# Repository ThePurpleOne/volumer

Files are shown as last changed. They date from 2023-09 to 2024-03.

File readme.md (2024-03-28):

# Volumer
Hardware module to easily control Individual Windows app just like the volume Mixer.

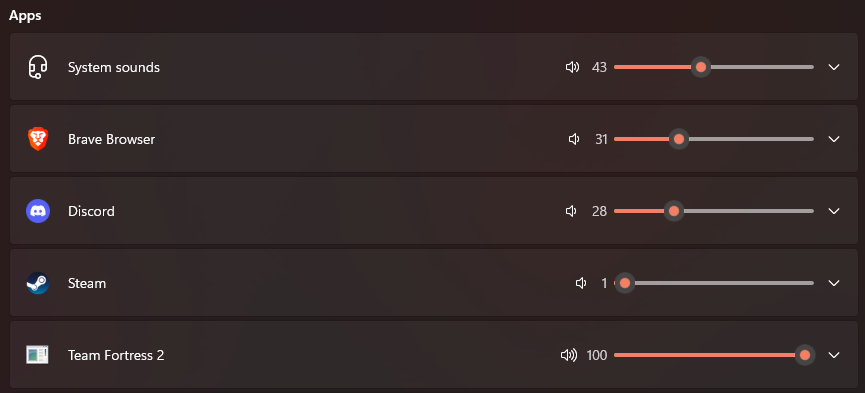
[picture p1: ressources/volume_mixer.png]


Accessing this window is a pain, especially if you're in game and you need to quickly lower that annoying SCREAMING discord friend in order to hear some terrorist footsteps.

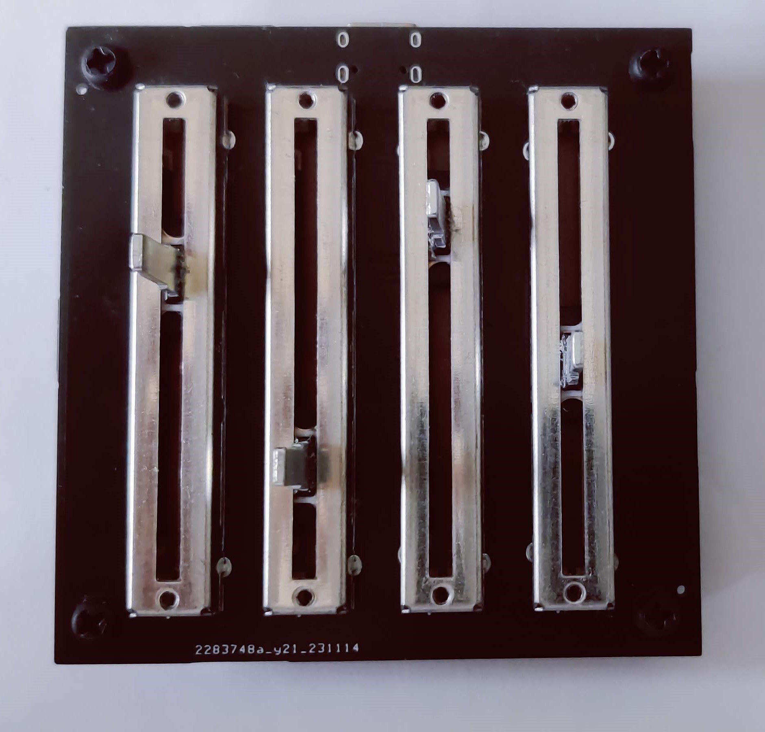
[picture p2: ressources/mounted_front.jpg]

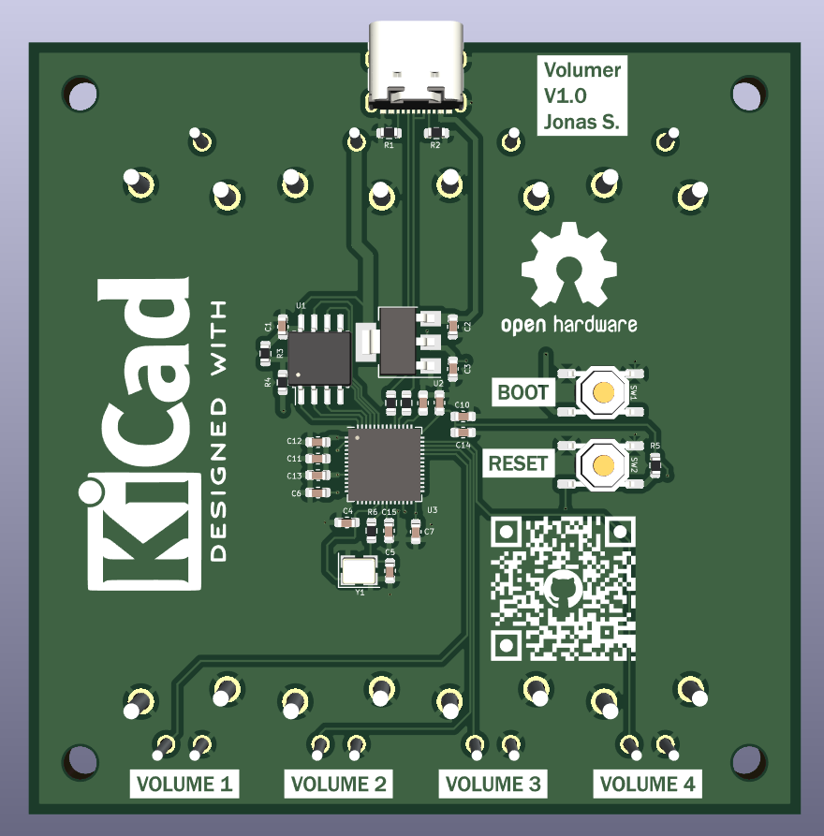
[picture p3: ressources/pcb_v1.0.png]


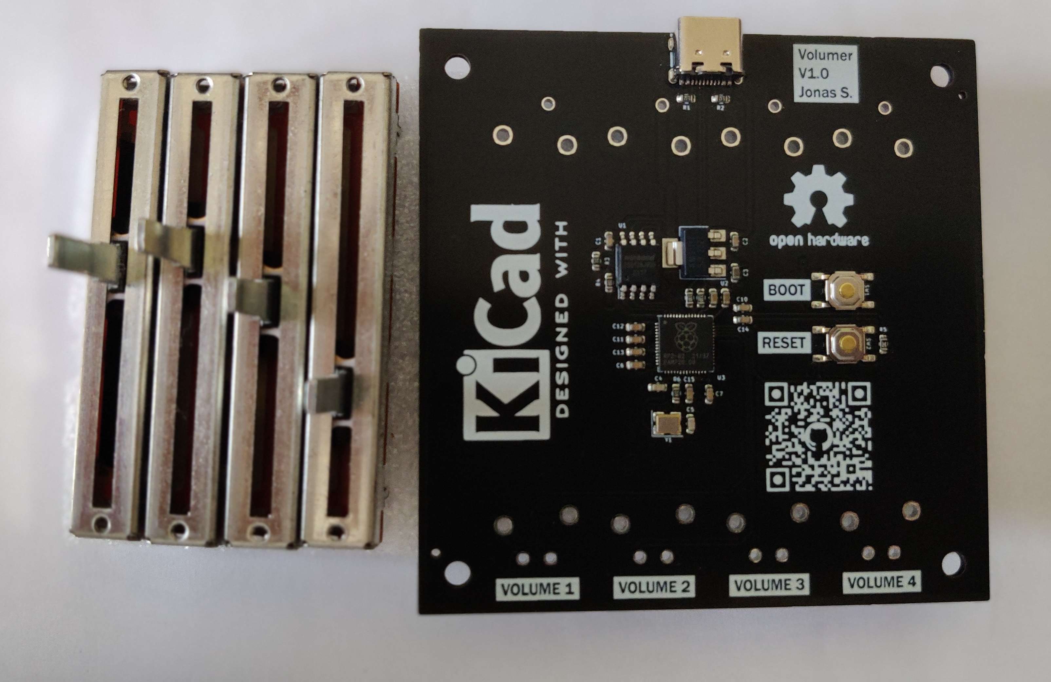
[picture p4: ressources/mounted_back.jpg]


> The PCB parts have been chosen for cheapest PCB Assembly with only 2 JLC PCB extended parts 

## How to setup
First you have to order your PCB and mount the potentiometers:
- [PCB Information](pcbs.md)
- [JLC PCB Order instructions](jlc_order.md)

Then you can install the software on the PC and flash the firmware on the Board:
- [Install the PC app](#pc-software)
- [Install/Update Board Firmware](#board-firmware)

## Case

There is no case for now, don't hesitate to contribute ! Here is the dimensions

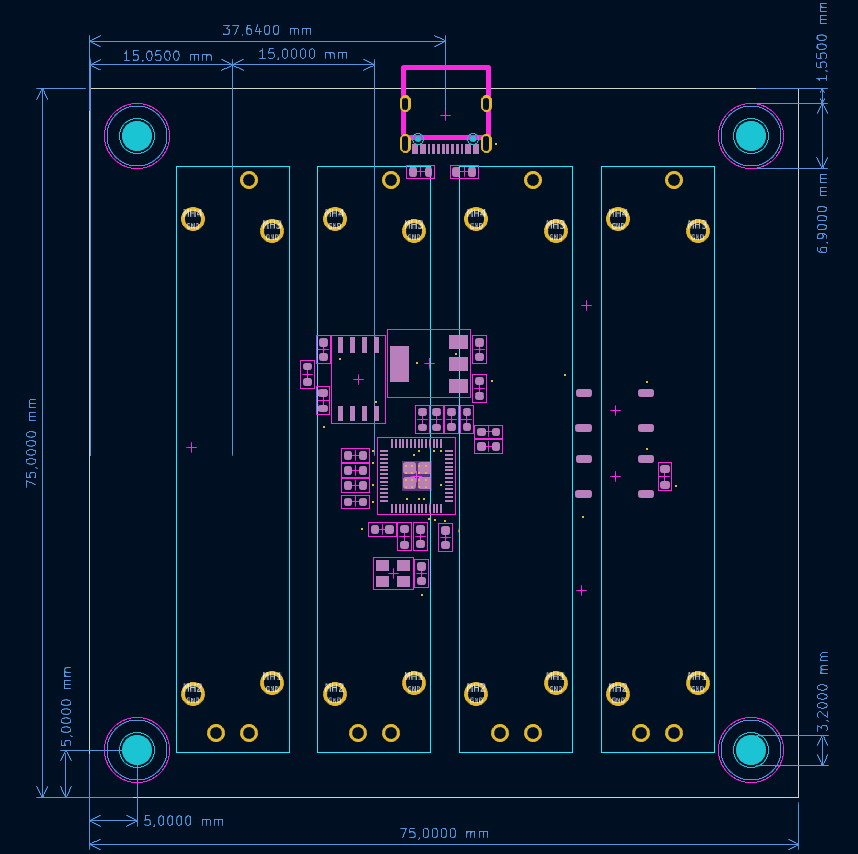
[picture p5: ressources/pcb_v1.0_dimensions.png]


## PC Software

[https://github.com/omriharel/deej](https://github.com/omriharel/deej)

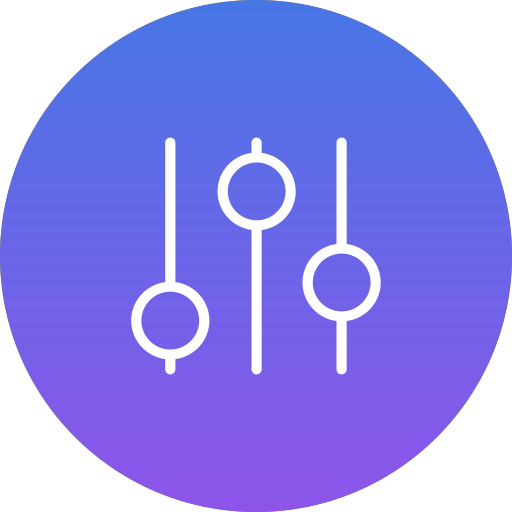
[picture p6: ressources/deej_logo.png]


For simplicity and not to reinvent the wheel, I'm using an opensource project called DEEJ, which actually does exactly what I want to do.

You only need to put the executable in the same folder as the config file and make a shortcut to the executable in the startup folder to have it start with windows.

config : [./src/pc/config.yaml](./src/pc/config.yaml) 

In the config, You can set which potentiometer controls which application and set the COM port of the board (The COM port is not automatically detected).

## Board Firmware 
You Circuit python or a UF2 compiled C program are available in the release page.

### C firmware
There is an already compiled UF2 file in the releases.

You can also compile the code yourself (need the RPI PICO SDK) and flash it to the board (Drag'n'drop in BOOTSEL mode). 

Compile with:
```bash
cd src/board/c
mkdir build
cd build
cmake ..
make
```

You can then flash the board with the generated UF2 file in the bin folder.

### Circuit Python
You can also use Circuitpython, which for a firmware that simple, i would not recommend it since it's just less reliable and efficient.

You'll first need to install Circuitpython firmware in the board and then push the program into it (Firmware and program available in release). 

To install the circuitpython firmware, you can simply drag and drop the UF2 file on the board after a boot with the BOOTSEL button pressed.

When Circuitpython is running, you can drag and drop the code.py file into the board Circuitpython mass storage (Not the one when bootsel is pressed).

## Download repo
Since there are submodules, you need to clone with the --recurse-submodules flag:

```bash
git clone --recurse-submodules
```

If you cloned without submodules
```bash
git submodule update --init
```

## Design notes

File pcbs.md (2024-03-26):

## PCB

### V1.0
[V1.0](./pcb/volumer_v1.0/)

[V1.0 Schematics](./pcb/volumer_v1.0/volumer_v1.0.pdf)



Version 1.0 should be the final version:
- Now has Mounting Holes
- Only 2 extended parts (JLCPCB)
- Only 2 layers
- Smaller board but same gap between sliders
- Need enclosure

### V0.2
[V0.2](./pcb/volumer_v0.2/)

[V0.2 Schematics](./pcb/volumer_v0.2/volumer_v02.pdf)

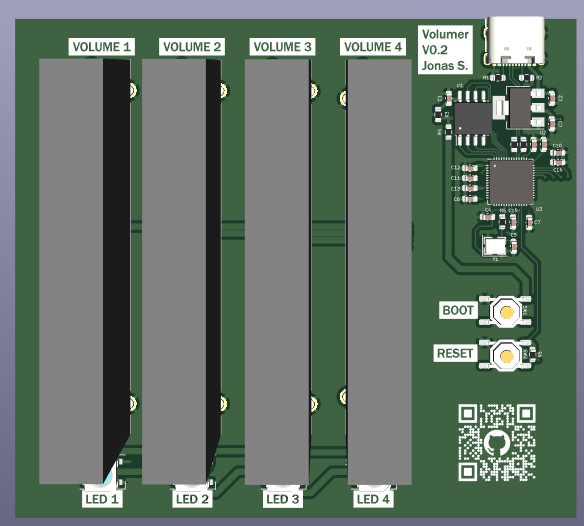
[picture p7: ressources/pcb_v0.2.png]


Version 0.2 is the first version that is actually usable:
- ERROR with the buttons (caused by 2 pins button in schematics but 4 pins footprint)
- Linear pots are nice and satisfying
- Size of pots is good
- Place between pots is good
- LEDs are useless
- PCB could be a lot smaller (pots mounted on other side of PCB)
- Broken QR code, freak this random qr code website, use [https://github.com/lyqht/styled-qr-code-generator](https://github.com/lyqht/styled-qr-code-generator)

### V0.1
[V0.1 folder](./pcb/volumer_v0.1/)

[V0.1 Schematics](./pcb/volumer_v0.1/volumer.pdf)

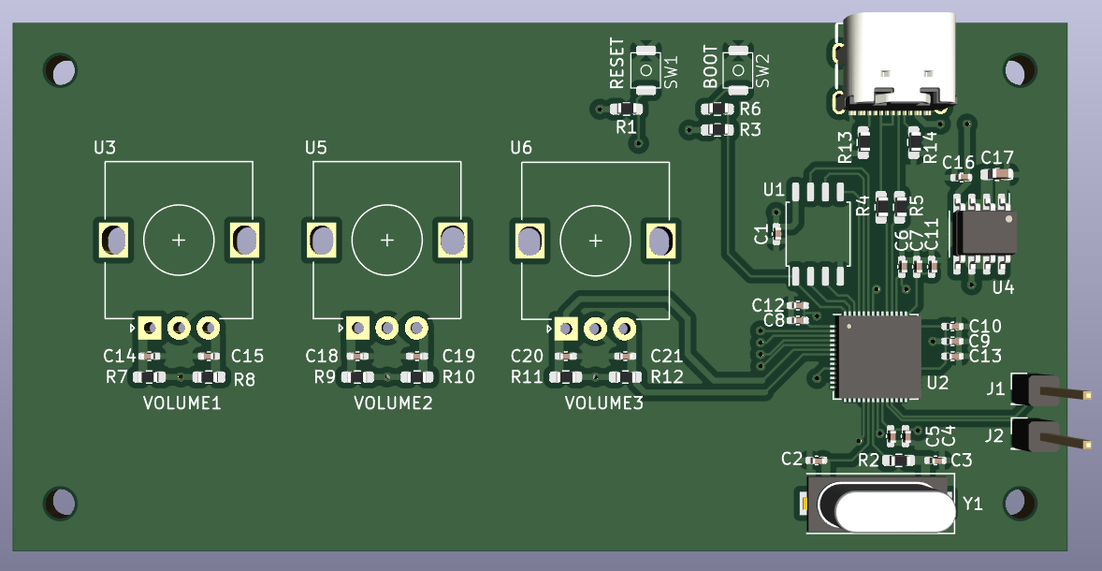
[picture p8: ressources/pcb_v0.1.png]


Version 0.1 was a prototype 
- Rotary encoders are not really satisfying to turn
- you can only turn one at the time
- Wrong rotary choice (really hard to turn and not clicky)
- Encoders too close to each other, cant pass a finger between them

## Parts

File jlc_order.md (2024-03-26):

# Buy the potentiometer

You'll need to buy 4 pots model `PTA45432015CPB503` from where you want since it's not available on JLCPCB.

# How to order on JLC PCB

## Step 1: Upload Gerber Files

Go to [JLCPCB](https://jlcpcb.com/), and upload the zip file containing the gerber. 

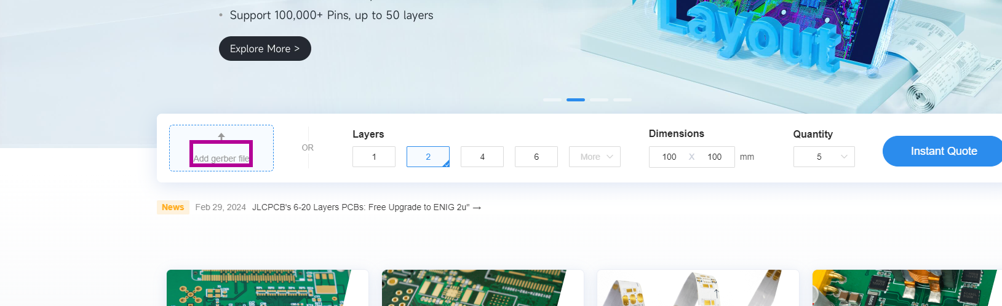
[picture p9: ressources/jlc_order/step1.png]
Upload Gerber Files


## Step 2: Check the PCB

Select the "Confirm production file" just to be sure, it will only cost you a few cents.

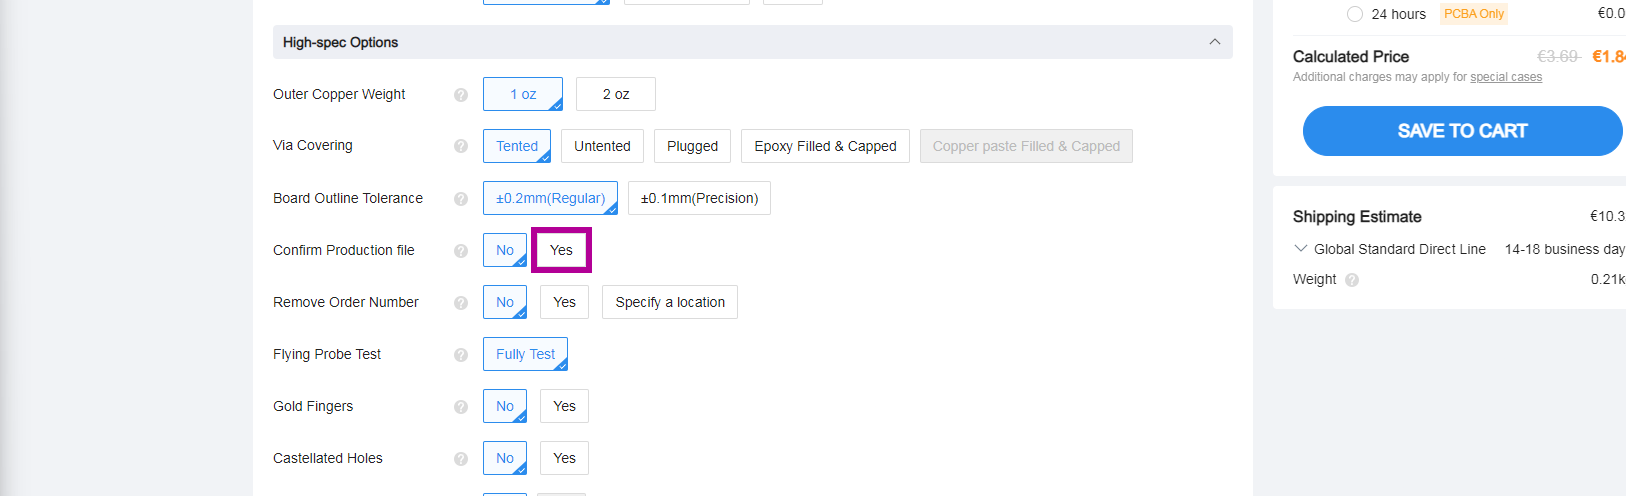
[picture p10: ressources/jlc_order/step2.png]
Check the PCB


> You can choose the PCB Color if you want

## Step 3: Select Assembly Service

Scroll and check the Assembly service

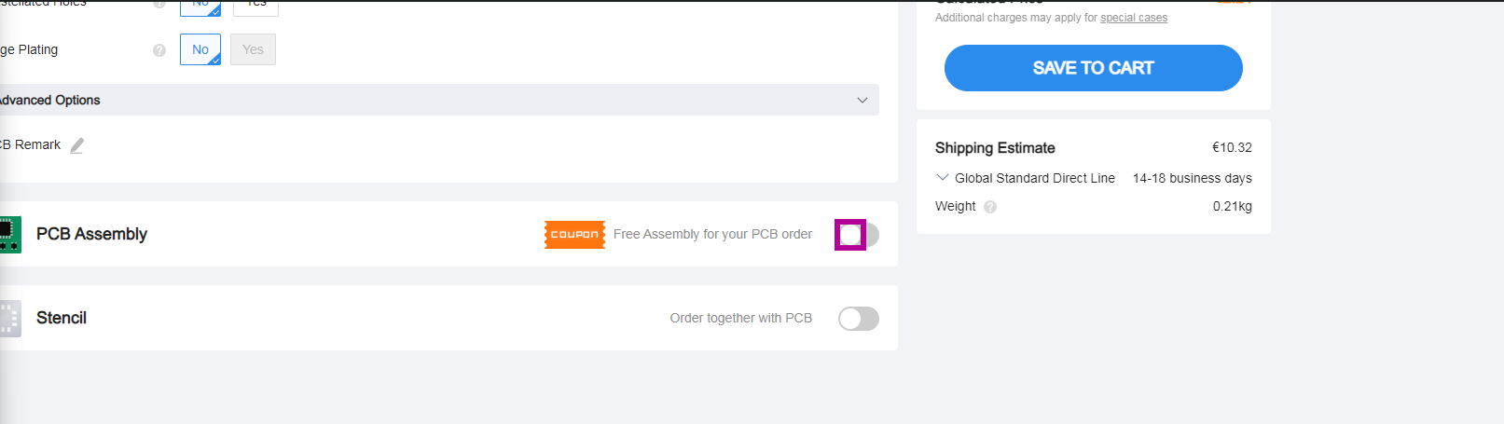
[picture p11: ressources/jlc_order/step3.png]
Select Assembly Service


## Step 4: Select only 2 PCB Assembly (Minimum)

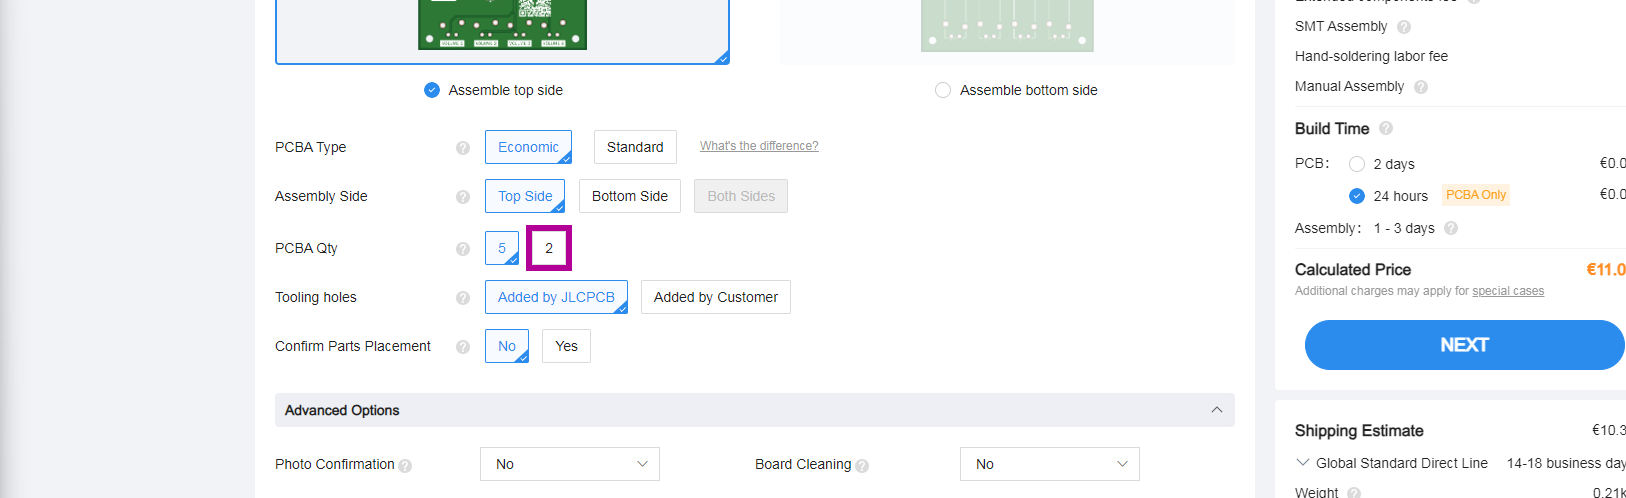
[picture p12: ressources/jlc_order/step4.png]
Select only 2 PCB Assembly (Minumum)


## Step 5: Confirm part placement

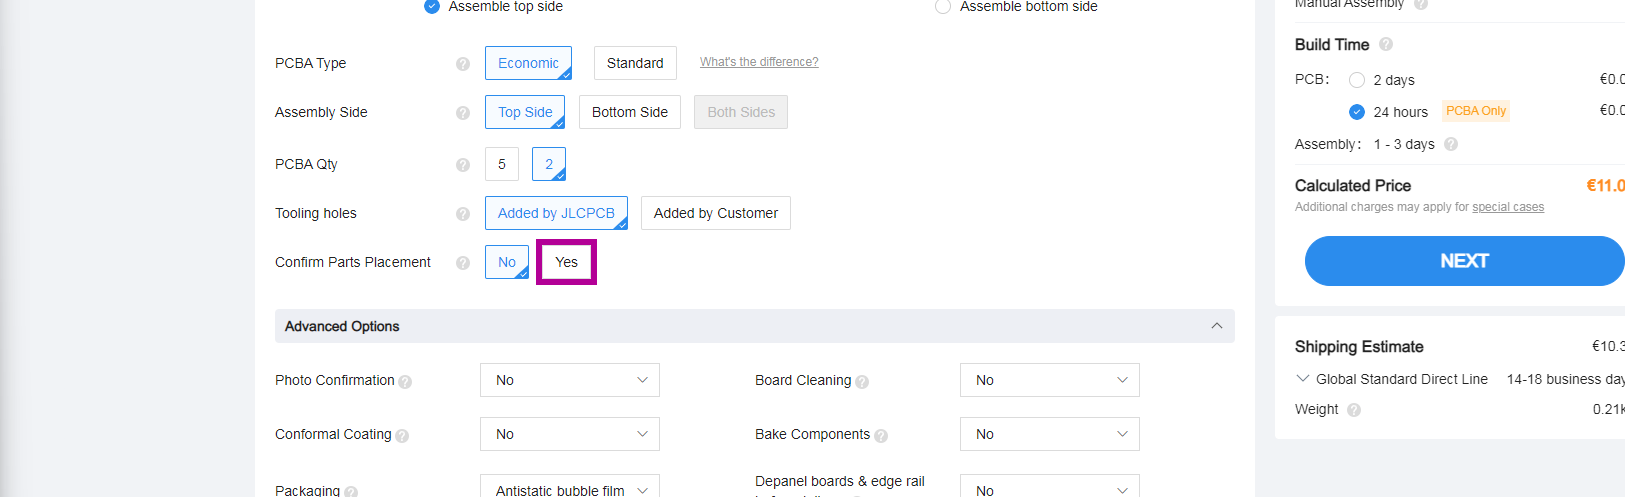
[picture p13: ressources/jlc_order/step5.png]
Confirm part placement


## Step 6: Validate PCBA setup

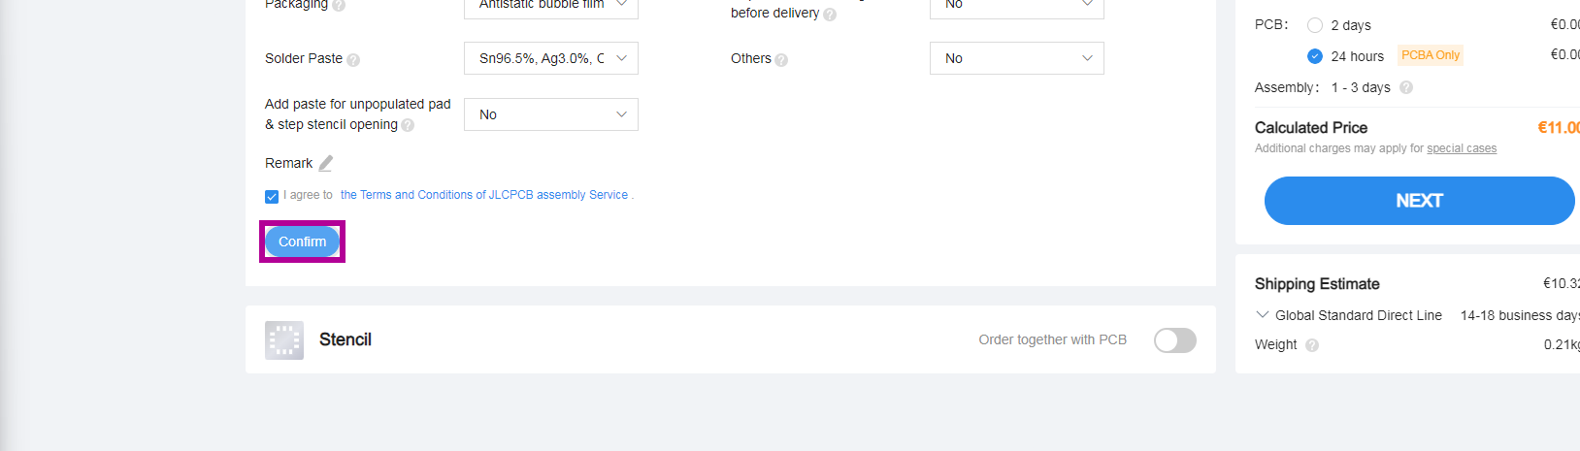
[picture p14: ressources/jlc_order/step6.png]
Validate PCBA setup


## Step 7: Check if there is anything wrong with the PCB view

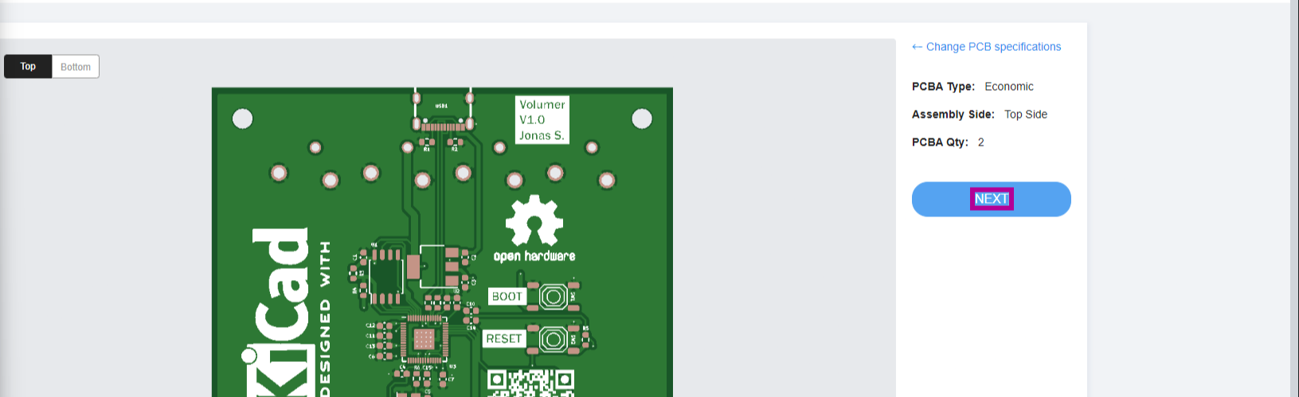
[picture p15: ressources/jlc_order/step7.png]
Check if there is anything wrong with the PCB view


## Step 8: Add the BOM

Add the BOM from the release page, it's called bom.csv

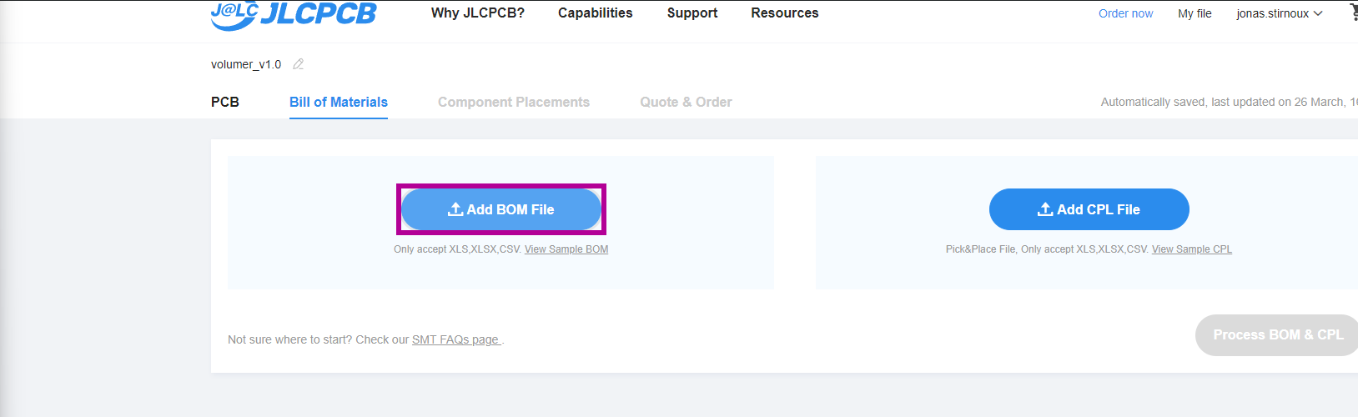
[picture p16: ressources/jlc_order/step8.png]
Add the BOM


## Step 9: Add the component placement

Add the component placement file from the release page, it's called placement.csv (Same as CPL)

Add the component placement

## Step 10: Confirm the components

Confirm the components

## Step 11: Check if there is issues with the components and click next

Check if there is issues with the components

## Step 12: The the produt descript as DIY (not important but you have to chose something)

The the produt descript as DIY

## Step 13: Save to cart

Save to cart

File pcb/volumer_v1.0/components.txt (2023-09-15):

Rotary encoder : https://www.lcsc.com/product-detail/span-style-background-color-ff0-Rotary-span-Encoders_ALPSALPINE-EC12E2430401_C470603.html

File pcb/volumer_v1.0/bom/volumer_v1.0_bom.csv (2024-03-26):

Reference | Value | Footprint | Qty | LCSC
C1,C2,C6,C7,C10,C11,C12,C13,C14,C15 | 100n | Capacitor_SMD:C_0603_1608Metric | 10 | C14663
C3 | 10u | Capacitor_SMD:C_0603_1608Metric | 1 | C19702
C4,C5 | 30p | Capacitor_SMD:C_0603_1608Metric | 2 | C1658
C8,C9 | 1u | Capacitor_SMD:C_0603_1608Metric | 2 | C15849
R1,R2 | 5k1 | Resistor_SMD:R_0603_1608Metric | 2 | C23186
R3,R5 | 10k | Resistor_SMD:R_0603_1608Metric | 2 | C25804
R4,R6 | 1k | Resistor_SMD:R_0603_1608Metric | 2 | C21190
R7,R8 | 33 | Resistor_SMD:R_0603_1608Metric | 2 | C23140
SW1,SW2 | SW_MEC_5E | push_button:TS-1187A-B-A-B | 2 | C318884
U1 | W25Q128JVS | Package_SO:SOIC-8_5.23x5.23mm_P1.27mm | 1 | C97521
U2 | LD1117S33TR | Package_TO_SOT_SMD:SOT-223-3_TabPin2 | 1 | C6186
U3 | RP2040 | Package_DFN_QFN:QFN-56-1EP_7x7mm_P0.4mm_EP3.2x3.2mm | 1 | C2040
USB1 | ~ | USBC:USBC_16P | 1 | C2765186
VR1,VR2,VR3,VR4 | slide_pot | PTA45432015CPB503 | 4
Y1 | 12Mhz | Crystal:Crystal_SMD_3225-4Pin_3.2x2.5mm | 1 | C9002

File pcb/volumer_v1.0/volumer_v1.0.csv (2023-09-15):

# | Reference | Qty | Value | Footprint | DNP
1 | C1, C4, C5, C8, C9, C10, C11, C12, C13, C16 | 10 | 100n | Capacitor_SMD:C_0402_1005Metric_Pad0.74x0.62mm_HandSolder
2 | C2, C3 | 2 | 27p | Capacitor_SMD:C_0402_1005Metric_Pad0.74x0.62mm_HandSolder
3 | C6, C7, C14, C15, C18, C19, C20, C21 | 8 | 1u | Capacitor_SMD:C_0402_1005Metric_Pad0.74x0.62mm_HandSolder
4 | C17 | 1 | 10u | Capacitor_SMD:C_0603_1608Metric_Pad1.08x0.95mm_HandSolder
5 | J1, J2 | 2 | Conn_01x01_Pin | Connector_PinHeader_2.54mm:PinHeader_1x01_P2.54mm_Vertical
6 | R1, R3, R7, R8, R9, R10, R11, R12 | 8 | 10k | Resistor_SMD:R_0603_1608Metric_Pad0.98x0.95mm_HandSolder
7 | R2, R6 | 2 | 1k | Resistor_SMD:R_0603_1608Metric_Pad0.98x0.95mm_HandSolder
8 | R4, R5 | 2 | 27 | Resistor_SMD:R_0603_1608Metric_Pad0.98x0.95mm_HandSolder
9 | R13, R14 | 2 | 5k1 | Resistor_SMD:R_0603_1608Metric_Pad0.98x0.95mm_HandSolder
10 | SW1, SW2 | 2 | TS-3025-B-C-B | push_button:lcsc_TS-3025-A-A-B_push_button
11 | U1 | 1 | W25Q128JVS | Package_SO:SOIC-8_5.23x5.23mm_P1.27mm
12 | U2 | 1 | RP2040 | Package_DFN_QFN:QFN-56-1EP_7x7mm_P0.4mm_EP3.2x3.2mm
13 | U3, U5, U6 | 3 | Rotary encoder | Rotary_Encoder:RotaryEncoder_Alps_EC12E_Vertical_H20mm
14 | U4 | 1 | LD1117D33 | Package_SO:SOIC-8_3.9x4.9mm_P1.27mm
15 | USB1 | 1 | ~ | USBC:USBC_16P
16 | Y1 | 1 | 12Mhz | Crystal:Crystal_SMD_HC49-SD

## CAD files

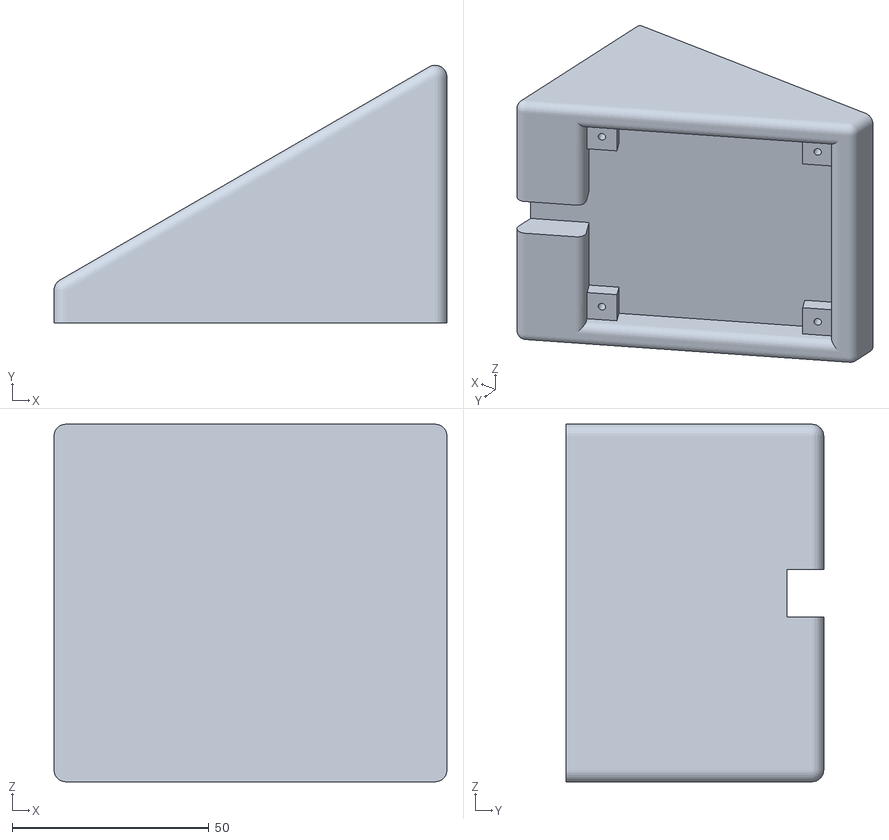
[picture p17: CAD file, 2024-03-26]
pcb/volumer_v1.0/case_v1.0.stl
100.0 x 65.5 x 91.0

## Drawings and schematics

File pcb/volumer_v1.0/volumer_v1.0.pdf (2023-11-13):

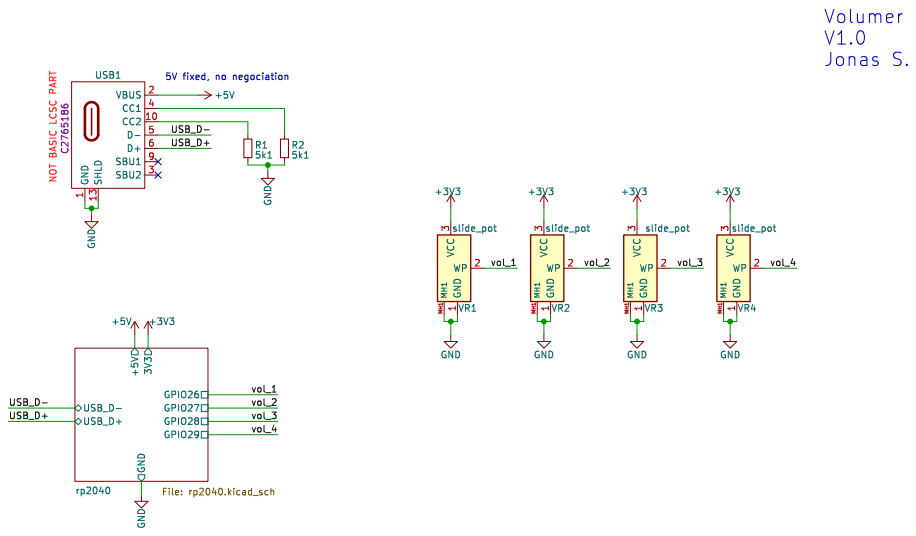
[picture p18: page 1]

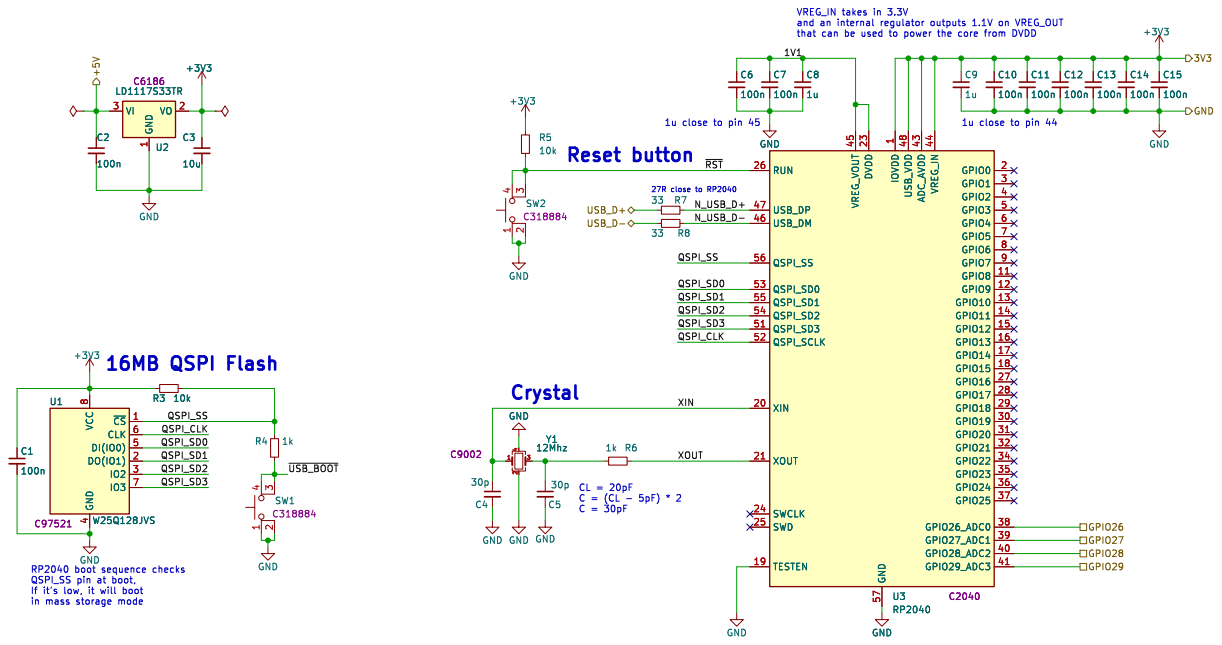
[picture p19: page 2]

1u close to pin 45 Reset button

1 GPIO8 11 GPIO9 12 GPIO10 13 GPIO11 14 GPIO12 15 GPIO13 16 GPIO14 17 GPIO15 18 TESTEN 19 GPIO0 2 XIN 20 XOUT 21 DVDD 23 SWCLK 24 SWD 25 RUN 26 GPIO16 27 GPIO17 28 GPIO18 29 GPIO1 3 GPIO19 30 GPIO20 31 GPIO21 32 GPIO22 34 GPIO23 35 GPIO24 36 GPIO25 37 GPIO26_ADC0 38 GPIO27_ADC1 39 GPIO2 4 GPIO28_ADC2 40 GPIO29_ADC3 41 ADC_AVDD 43 VREG_IN 44 VREG_VOUT 45 USB_DM 46 USB_DP 47 USB_VDD 48 GPIO3 5 QSPI_SD3 51 QSPI_SCLK 52 QSPI_SD0 53 QSPI_SD2 54 QSPI_SD1 55 QSPI_SS 56 GND 57 GPIO4 6 GPIO5 7 GPIO6 8 GPIO7 9 U3 RP2040 C2040 GND GND

1 GPIO8 11 GPIO9 12 GPIO10 13 GPIO11 14 GPIO12 15 GPIO13 16 GPIO14 17 GPIO15 18 TESTEN 19 GPIO0 2 XIN 20 XOUT 21 DVDD 23 SWCLK 24 SWD 25 RUN 26 GPIO16 27 GPIO17 28 GPIO18 29 GPIO1 3 GPIO19 30 GPIO20 31 GPIO21 32 GPIO22 34 GPIO23 35 GPIO24 36 GPIO25 37 GPIO26_ADC0 38 GPIO27_ADC1 39 GPIO2 4 GPIO28_ADC2 40 GPIO29_ADC3 41 ADC_AVDD 43 VREG_IN 44 VREG_VOUT 45 USB_DM 46 USB_DP 47 USB_VDD 48 GPIO3 5 QSPI_SD3 51 QSPI_SCLK 52 QSPI_SD0 53 QSPI_SD2 54 QSPI_SD1 55 QSPI_SS 56 GND 57 GPIO4 6 GPIO5 7 GPIO6 8 GPIO7 9 GND

27R close to RP2040 RP2040 boot sequence checks QSPI_SS pin at boot,

If it's low, it will boot
in mass storage mode

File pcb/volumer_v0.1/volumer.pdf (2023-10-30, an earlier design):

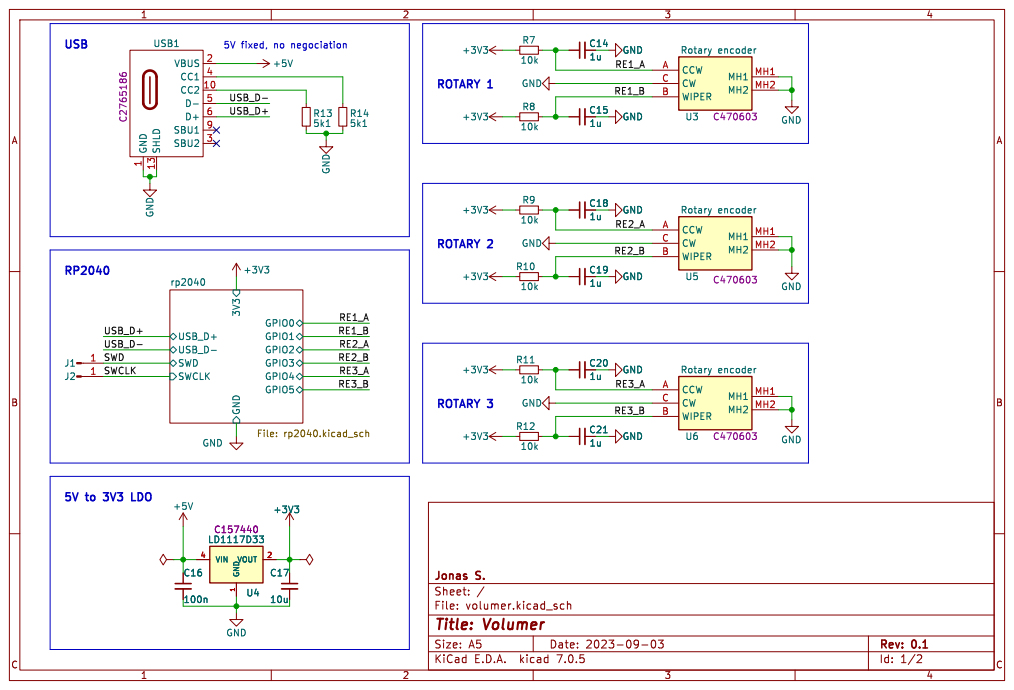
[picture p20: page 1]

Id: 1/2 Title: Volumer File: volumer.kicad_sch Sheet: / Jonas S. 3V3 USB_D+ USB_D- SWD

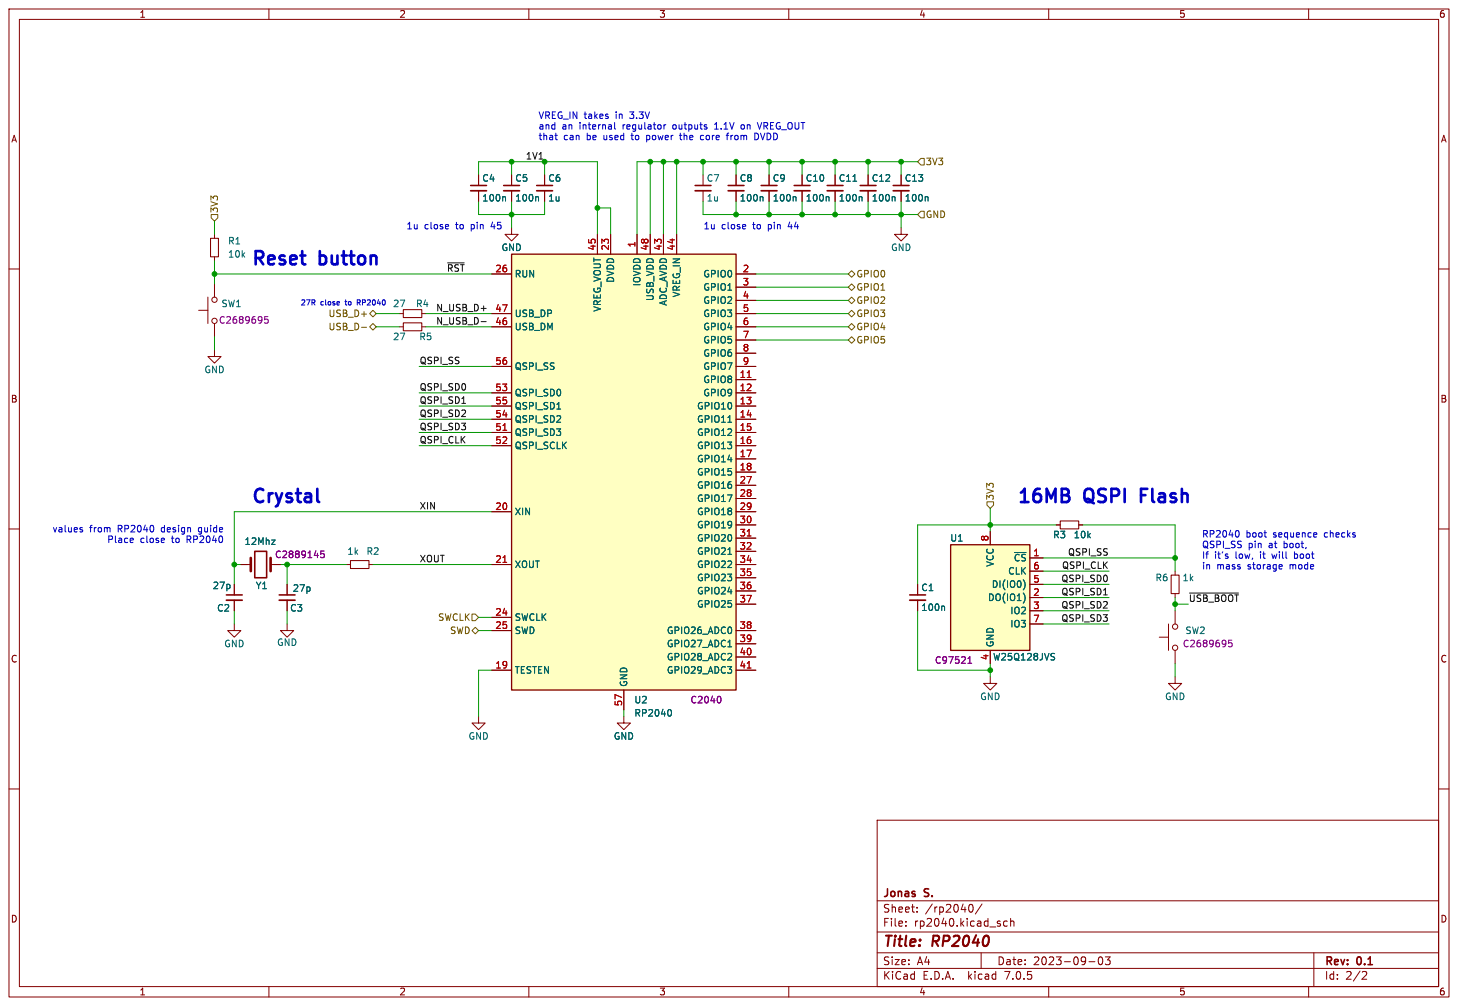
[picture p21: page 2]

that can be used to power the core from DVDD

1 GPIO8 11 GPIO9 12 GPIO10 13 GPIO11 14 GPIO12 15 GPIO13 16 GPIO14 17 GPIO15 18 TESTEN 19 GPIO0 2 XIN 20 XOUT 21 DVDD 23 SWCLK 24 SWD 25 RUN 26 GPIO16 27 GPIO17 28 GPIO18 29 GPIO1 3 GPIO19 30 GPIO20 31 GPIO21 32 GPIO22 34 GPIO23 35 GPIO24 36 GPIO25 37 GPIO26_ADC0 38 GPIO27_ADC1 39 GPIO2 4 GPIO28_ADC2 40 GPIO29_ADC3 41 ADC_AVDD 43 VREG_IN 44 VREG_VOUT 45 USB_DM 46 USB_DP 47 USB_VDD 48 GPIO3 5 QSPI_SD3 51 QSPI_SCLK 52 QSPI_SD0 53 QSPI_SD2 54 QSPI_SD1 55 QSPI_SS 56 GND 57 GPIO4 6 GPIO5 7 GPIO6 8 GPIO7 9 U2 RP2040 C2040

1 GPIO8 11 GPIO9 12 GPIO10 13 GPIO11 14 GPIO12 15 GPIO13 16 GPIO14 17 GPIO15 18 TESTEN 19 GPIO0 2 XIN 20 XOUT 21 DVDD 23 SWCLK 24 SWD 25 RUN 26 GPIO16 27 GPIO17 28 GPIO18 29 GPIO1 3 GPIO19 30 GPIO20 31 GPIO21 32 GPIO22 34 GPIO23 35 GPIO24 36 GPIO25 37 GPIO26_ADC0 38 GPIO27_ADC1 39 GPIO2 4 GPIO28_ADC2 40 GPIO29_ADC3 41 ADC_AVDD 43 VREG_IN 44 VREG_VOUT 45 USB_DM 46 USB_DP 47 USB_VDD 48 GPIO3 5 QSPI_SD3 51 QSPI_SCLK 52 QSPI_SD0 53 QSPI_SD2 54 QSPI_SD1 55 QSPI_SS 56 GND 57 GPIO4 6 GPIO5 7 GPIO6 8 GPIO7 9 GND

If it's low, it will boot
in mass storage mode

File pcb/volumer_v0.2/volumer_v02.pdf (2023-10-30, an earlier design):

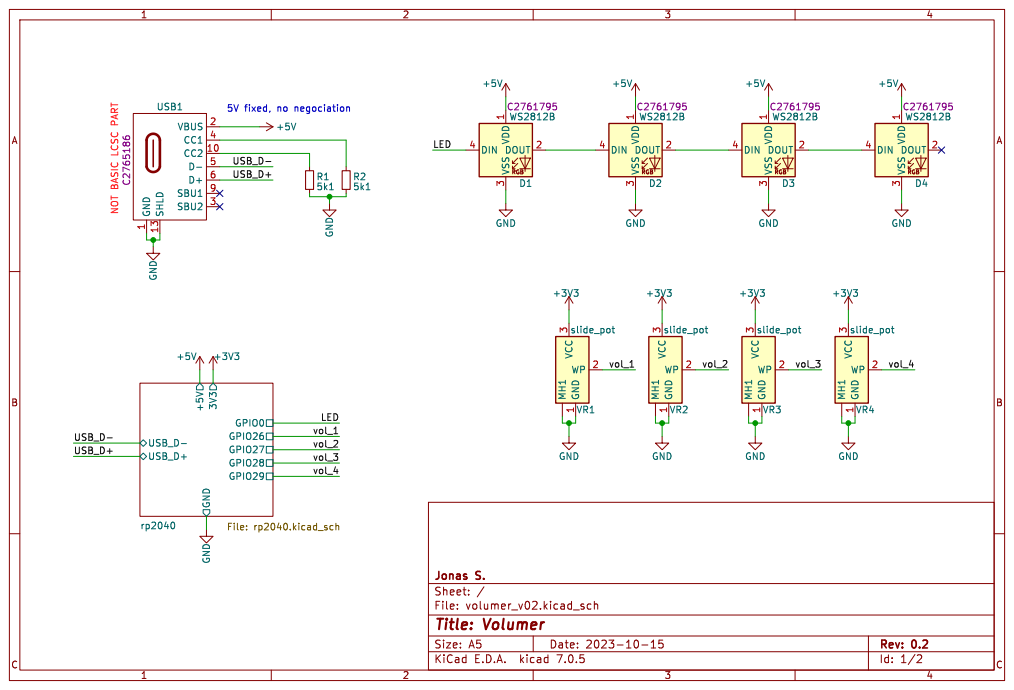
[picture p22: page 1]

5V fixed, no negociation NOT BASIC LCSC PART

1 CC2 10 SHLD 13 VBUS 2 SBU2 3 CC1 4 D- 5 D+ 6 SBU1 9 USB1 C2765186 +5V GND GND

Id: 1/2 Title: Volumer File: volumer_v02.kicad_sch Sheet: / Jonas S. GPIO27 GPIO26 GPIO28 GPIO29 3V3 GND

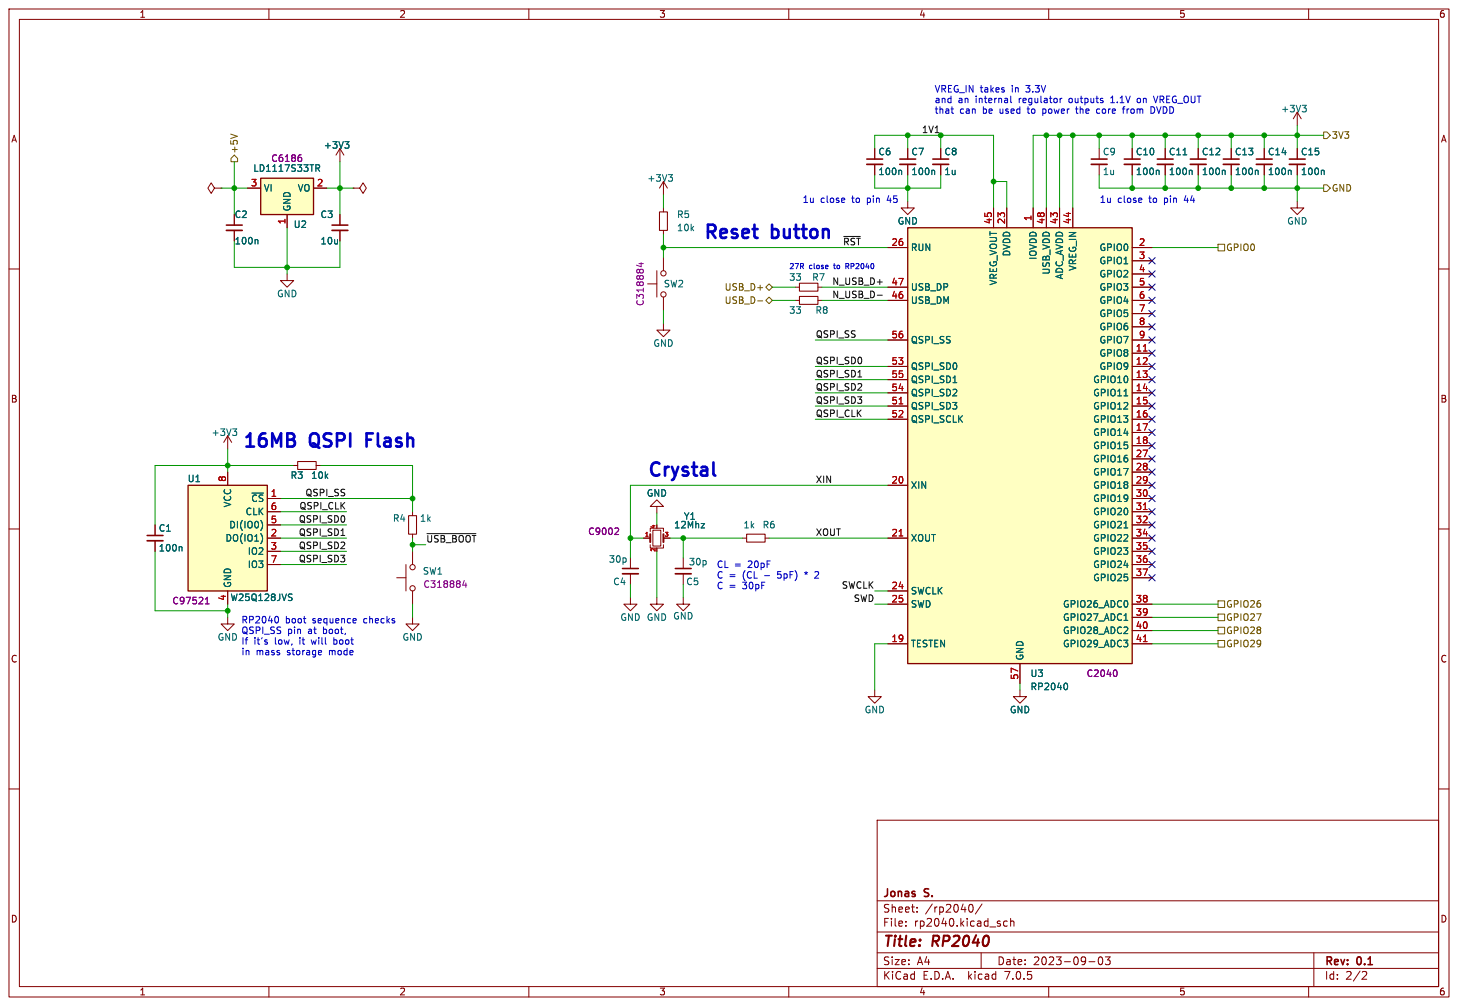
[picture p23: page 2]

that can be used to power the core from DVDD
100n GND

1 GPIO8 11 GPIO9 12 GPIO10 13 GPIO11 14 GPIO12 15 GPIO13 16 GPIO14 17 GPIO15 18 TESTEN 19 GPIO0 2 XIN 20 XOUT 21 DVDD 23 SWCLK 24 SWD 25 RUN 26 GPIO16 27 GPIO17 28 GPIO18 29 GPIO1 3 GPIO19 30 GPIO20 31 GPIO21 32 GPIO22 34 GPIO23 35 GPIO24 36 GPIO25 37 GPIO26_ADC0 38 GPIO27_ADC1 39 GPIO2 4 GPIO28_ADC2 40 GPIO29_ADC3 41 ADC_AVDD 43 VREG_IN 44 VREG_VOUT 45 USB_DM 46 USB_DP 47 USB_VDD 48 GPIO3 5 QSPI_SD3 51 QSPI_SCLK 52 QSPI_SD0 53 QSPI_SD2 54 QSPI_SD1 55 QSPI_SS 56 GND 57 GPIO4 6 GPIO5 7 GPIO6 8 GPIO7 9 C8

1 GPIO8 11 GPIO9 12 GPIO10 13 GPIO11 14 GPIO12 15 GPIO13 16 GPIO14 17 GPIO15 18 TESTEN 19 GPIO0 2 XIN 20 XOUT 21 DVDD 23 SWCLK 24 SWD 25 RUN 26 GPIO16 27 GPIO17 28 GPIO18 29 GPIO1 3 GPIO19 30 GPIO20 31 GPIO21 32 GPIO22 34 GPIO23 35 GPIO24 36 GPIO25 37 GPIO26_ADC0 38 GPIO27_ADC1 39 GPIO2 4 GPIO28_ADC2 40 GPIO29_ADC3 41 ADC_AVDD 43 VREG_IN 44 VREG_VOUT 45 USB_DM 46 USB_DP 47 USB_VDD 48 GPIO3 5 QSPI_SD3 51 QSPI_SCLK 52 QSPI_SD0 53 QSPI_SD2 54 QSPI_SD1 55 QSPI_SS 56 GND 57 GPIO4 6 GPIO5 7 GPIO6 8 GPIO7 9 U3 RP2040 C2040 GND

RP2040 boot sequence checks QSPI_SS pin at boot,

If it's low, it will boot
in mass storage mode

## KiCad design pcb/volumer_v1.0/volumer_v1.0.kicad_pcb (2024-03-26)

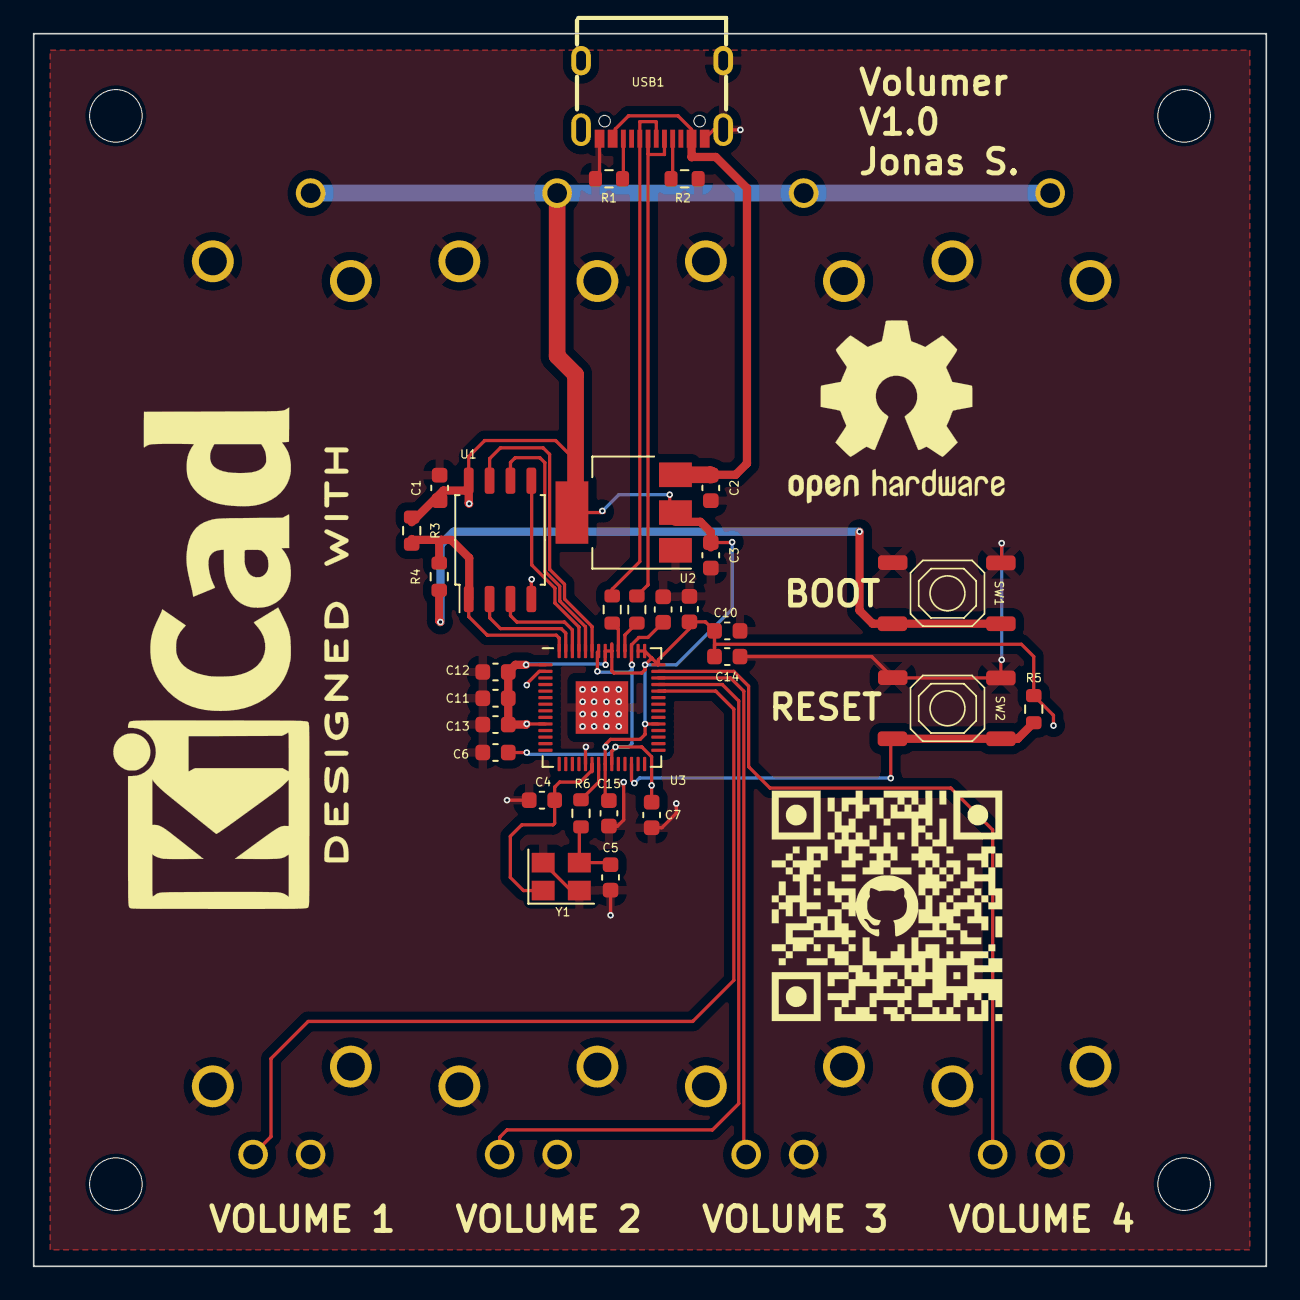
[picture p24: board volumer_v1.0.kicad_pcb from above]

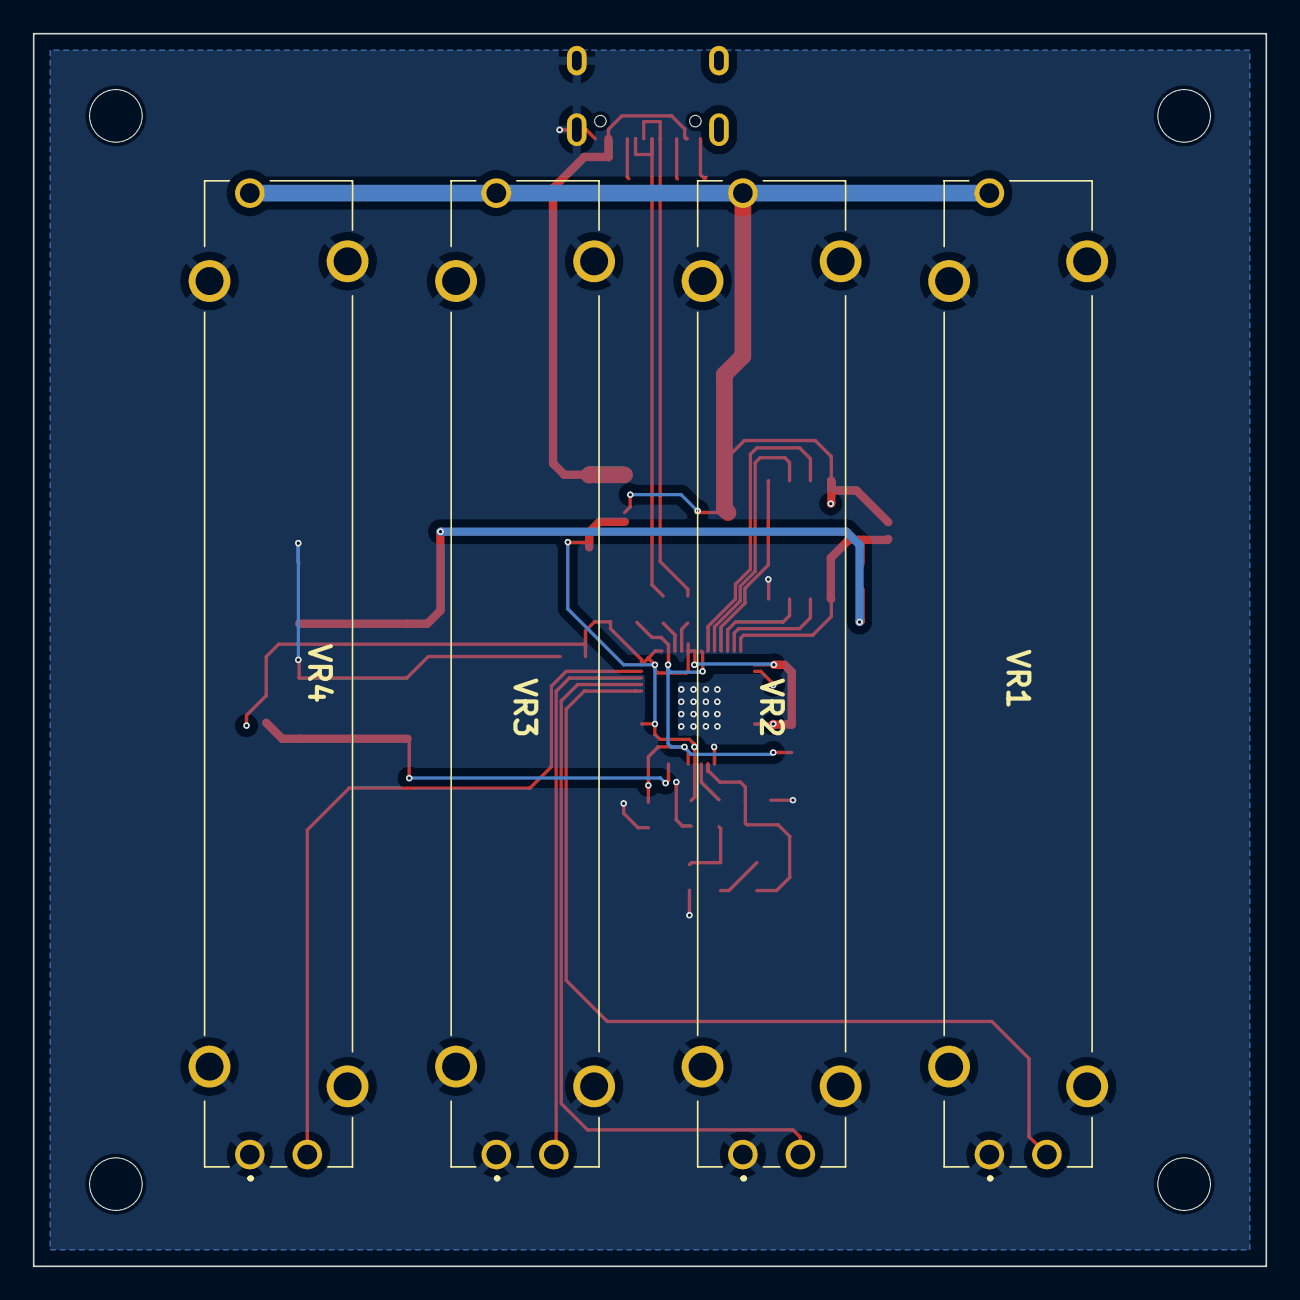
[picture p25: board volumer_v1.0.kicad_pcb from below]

Board: 2 copper layers, 75.0 x 75.0 mm, 39 parts (4 on the bottom side), 25 nets.

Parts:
C1, C2, C6, C7, C10, C11, C12, C13, C14, C15: 100n; C_0603_1608Metric
C3: 10u; C_0603_1608Metric
C4, C5: 30p; C_0603_1608Metric
C8, C9: 1u; C_0603_1608Metric
MH: MountingHole_3.2mm_M3
MH#2, MH#3, MH#4: MountingHole_3.2mm_M3
QR: LOGO; qr
R1, R2: 5k1; R_0603_1608Metric
R3, R5: 10k; R_0603_1608Metric
R4, R6: 1k; R_0603_1608Metric
R7, R8: 33; R_0603_1608Metric
SW1, SW2: SW_MEC_5E; TS-1187A-B-A-B
U1: W25Q128JVS; SOIC-8_5.23x5.23mm_P1.27mm
U2: LD1117S33TR; SOT-223-3_TabPin2
U3: RP2040; QFN-56-1EP_7x7mm_P0.4mm_EP3.2x3.2mm
USB1: USBC_16P
VR1, VR2, VR3, VR4: slide_pot; PTA45432015CPB503
Y1: 12Mhz; Crystal_SMD_3225-4Pin_3.2x2.5mm

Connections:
+3V3: C1.1, C3.1, C9.1, C10.1, C11.1, C12.1, C13.1, C14.1, C15.1, R3.1, R5.1, U1.8 (VCC), U2.2 (VO), U3.1 (IOVDD), U3.10 (IOVDD), U3.22 (IOVDD), U3.33 (IOVDD), U3.42 (IOVDD), U3.43 (ADC_AVDD), U3.44 (VREG_IN), U3.48 (USB_VDD), U3.49 (IOVDD), VR1.3 (VCC), VR2.3 (VCC), VR3.3 (VCC), VR4.3 (VCC)
+5V: C2.1, U2.3 (VI), USB1.2 (VBUS), USB1.11 (VBUS)
/USB_D+: R7.2, USB1.6 (D+), USB1.8 (D+)
/USB_D-: R8.2, USB1.5 (D-), USB1.7 (D-)
/rp2040/1V1: C6.1, C7.1, C8.1, U3.23 (DVDD), U3.45 (VREG_VOUT), U3.50 (DVDD)
/rp2040/N_USB_D+: R7.1, U3.47 (USB_DP)
/rp2040/N_USB_D-: R8.1, U3.46 (USB_DM)
/rp2040/QSPI_CLK: U1.6 (CLK), U3.52 (QSPI_SCLK)
/rp2040/QSPI_SD0: U1.5 (DI(IO0)), U3.53 (QSPI_SD0)
/rp2040/QSPI_SD1: U1.2 (DO(IO1)), U3.55 (QSPI_SD1)
/rp2040/QSPI_SD2: U1.3 (IO2), U3.54 (QSPI_SD2)
/rp2040/QSPI_SD3: U1.7 (IO3), U3.51 (QSPI_SD3)
/rp2040/QSPI_SS: R3.2, R4.2, U1.1 (~CS), U3.56 (QSPI_SS)
/rp2040/XIN: C4.1, U3.20 (XIN), Y1.1
/rp2040/XOUT: R6.1, U3.21 (XOUT)
/rp2040/~RST: R5.2, SW2.3 (K), SW2.4 (A), U3.26 (RUN)
/rp2040/~USB_BOOT: R4.1, SW1.3 (K), SW1.4 (A)
/vol_1: U3.38 (GPIO26_ADC0), VR1.2 (WP)
/vol_2: U3.39 (GPIO27_ADC1), VR2.2 (WP)
/vol_3: U3.40 (GPIO28_ADC2), VR3.2 (WP)
/vol_4: U3.41 (GPIO29_ADC3), VR4.2 (WP)
GND: C1.2, C2.2, C3.2, C4.2, C5.2, C6.2, C7.2, C8.2, C9.2, C10.2, C11.2, C12.2, C13.2, C14.2, C15.2, R1.2, R2.2, SW1.1, SW1.2, SW2.1, SW2.2, U1.4 (GND), U2.1 (GND), U3.19 (TESTEN), U3.57 (GND), USB1.1 (GND), USB1.12 (GND), USB1.13 (SHLD), VR1.1 (GND), VR1.MH1, VR1.MH2, VR1.MH3, VR1.MH4, VR2.1 (GND), VR2.MH1, VR2.MH2, VR2.MH3, VR2.MH4, VR3.1 (GND), VR3.MH1, VR3.MH2, VR3.MH3, VR3.MH4, VR4.1 (GND), VR4.MH1, VR4.MH2, VR4.MH3, VR4.MH4, Y1.2, Y1.4
unnamed: C5.1, R6.2, Y1.3
unnamed: R2.1, USB1.4 (CC1)
unnamed: R1.1, USB1.10 (CC2)

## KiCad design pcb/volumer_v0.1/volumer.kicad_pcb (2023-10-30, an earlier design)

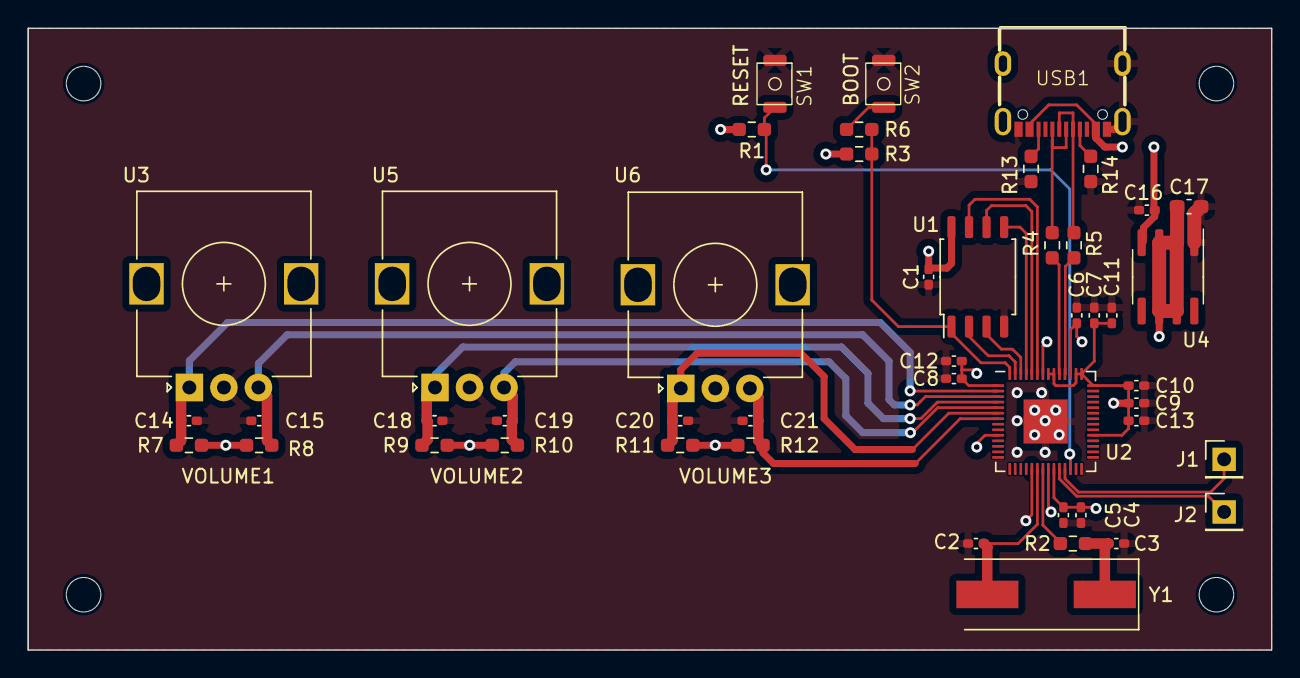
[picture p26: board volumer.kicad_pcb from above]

Board: 4 copper layers, 90.0 x 45.0 mm, 47 parts (0 on the bottom side), 29 nets.

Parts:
C1, C4, C5, C8, C9, C10, C11, C12, C13, C16: 100n; C_0402_1005Metric_Pad0.74x0.62mm_HandSolder
C2, C3: 27p; C_0402_1005Metric_Pad0.74x0.62mm_HandSolder
C6, C7, C14, C15, C18, C19, C20, C21: 1u; C_0402_1005Metric_Pad0.74x0.62mm_HandSolder
C17: 10u; C_0603_1608Metric_Pad1.08x0.95mm_HandSolder
J1, J2: Conn_01x01_Pin; PinHeader_1x01_P2.54mm_Vertical
R1, R3, R7, R8, R9, R10, R11, R12: 10k; R_0603_1608Metric_Pad0.98x0.95mm_HandSolder
R2, R6: 1k; R_0603_1608Metric_Pad0.98x0.95mm_HandSolder
R4, R5: 27; R_0603_1608Metric_Pad0.98x0.95mm_HandSolder
R13, R14: 5k1; R_0603_1608Metric_Pad0.98x0.95mm_HandSolder
SW1, SW2: TS-3025-B-C-B; lcsc_TS-3025-A-A-B_push_button
U1: W25Q128JVS; SOIC-8_5.23x5.23mm_P1.27mm
U2: RP2040; QFN-56-1EP_7x7mm_P0.4mm_EP3.2x3.2mm
U3, U5, U6: Rotary encoder; RotaryEncoder_Alps_EC12E_Vertical_H20mm
U4: LD1117D33; SOIC-8_3.9x4.9mm_P1.27mm
USB1: USBC_16P
Y1: 12Mhz; Crystal_SMD_HC49-SD

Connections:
+3V3: C1.1, C7.1, C8.1, C9.1, C10.1, C11.1, C12.1, C13.1, C17.1, R1.1, R3.1, R7.1, R8.1, R9.1, R10.1, R11.1, R12.1, U1.8 (VCC), U2.1 (IOVDD), U2.10 (IOVDD), U2.22 (IOVDD), U2.33 (IOVDD), U2.42 (IOVDD), U2.43 (ADC_AVDD), U2.44 (VREG_IN), U2.48 (USB_VDD), U2.49 (IOVDD), U4.2 (VOUT), U4.3 (VOUT@2), U4.6 (VOUT@3), U4.7 (VOUT@4)
+5V: C16.1, U4.4 (VIN), USB1.2 (VBUS), USB1.11 (VBUS)
/RE1_A: C14.1, R7.2, U2.2 (GPIO0), U3.A (CCW)
/RE1_B: C15.1, R8.2, U2.3 (GPIO1), U3.B (WIPER)
/RE2_A: C18.1, R9.2, U2.4 (GPIO2), U5.A (CCW)
/RE2_B: C19.1, R10.2, U2.5 (GPIO3), U5.B (WIPER)
/RE3_A: C20.1, R11.2, U2.6 (GPIO4), U6.A (CCW)
/RE3_B: C21.1, R12.2, U2.7 (GPIO5), U6.B (WIPER)
/SWCLK: J2.1, U2.24 (SWCLK)
/SWD: J1.1, U2.25 (SWD)
/USB_D+: R4.2, USB1.6 (D+), USB1.8 (D+)
/USB_D-: R5.2, USB1.5 (D-), USB1.7 (D-)
/rp2040/1V1: C4.1, C5.1, C6.1, U2.23 (DVDD), U2.45 (VREG_VOUT), U2.50 (DVDD)
/rp2040/N_USB_D+: R4.1, U2.47 (USB_DP)
/rp2040/N_USB_D-: R5.1, U2.46 (USB_DM)
/rp2040/QSPI_CLK: U1.6 (CLK), U2.52 (QSPI_SCLK)
/rp2040/QSPI_SD0: U1.5 (DI(IO0)), U2.53 (QSPI_SD0)
/rp2040/QSPI_SD1: U1.2 (DO(IO1)), U2.55 (QSPI_SD1)
/rp2040/QSPI_SD2: U1.3 (IO2), U2.54 (QSPI_SD2)
/rp2040/QSPI_SD3: U1.7 (IO3), U2.51 (QSPI_SD3)
/rp2040/QSPI_SS: R3.2, R6.2, U1.1 (~CS), U2.56 (QSPI_SS)
/rp2040/XIN: C2.1, U2.20 (XIN), Y1.2
/rp2040/XOUT: R2.1, U2.21 (XOUT)
/rp2040/~RST: R1.2, SW1.2, U2.26 (RUN)
/rp2040/~USB_BOOT: R6.1, SW2.2
GND: C1.2, C2.2, C3.2, C4.2, C5.2, C6.2, C7.2, C8.2, C9.2, C10.2, C11.2, C12.2, C13.2, C14.2, C15.2, C16.2, C17.2, C18.2, C19.2, C20.2, C21.2, R13.2, R14.2, SW1.1, SW2.1, U1.4 (GND), U2.19 (TESTEN), U2.57 (GND), U3.C (CW), U4.1 (GND), U5.C (CW), U6.C (CW), USB1.1 (GND), USB1.12 (GND), USB1.13 (SHLD)
unnamed: C3.1, R2.2, Y1.1
unnamed: R14.1, USB1.4 (CC1)
unnamed: R13.1, USB1.10 (CC2)

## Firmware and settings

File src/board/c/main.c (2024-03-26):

/**
 * @file main.c
 * @author Jonas S.
 * @brief 
 * @version 0.1
 * @date 26/03/2024
 * 
 */

#include <stdio.h>
#include "pico/stdlib.h"
#include "hardware/gpio.h"
#include "hardware/adc.h"

int main() 
{
	stdio_init_all();
	adc_init();

	uint pins[] = {26, 27, 28, 29};  // Replace with the actual GPIO pins you want to use

	for (int i = 0; i < sizeof(pins) / sizeof(pins[0]); i++) 
		adc_gpio_init(pins[i]);

	while (1) 
	{
		int scaled_vals[sizeof(pins) / sizeof(pins[0])];

		for (int i = 0; i < sizeof(pins) / sizeof(pins[0]); i++) 
		{
			adc_select_input(i);  // Select the ADC input for this iteration
			scaled_vals[i] = adc_read() >> 2;
		}

		printf("%d|%d|%d|%d|%d\n", 	scaled_vals[0], 
									scaled_vals[1], 
									scaled_vals[2], 
									scaled_vals[3], 
									scaled_vals[0]);

		sleep_ms(10);
	}
}

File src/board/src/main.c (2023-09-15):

#include <stdio.h>
#include "pico/stdlib.h"
#include "pico/binary_info.h"
#include "pico/unique_id.h"
#include "hardware/gpio.h"
#include "hardware/irq.h"
#include "hardware/pio.h"
#include "usb/usb.h"
#include "usb/hid.h"

// Define the VID and PID for your custom HID device
#define VENDOR_ID 0x1234
#define PRODUCT_ID 0x5678

// Custom report IDs
#define CUSTOM_REPORT_ID_1 0x01
#define CUSTOM_REPORT_ID_2 0x02
#define CUSTOM_REPORT_ID_3 0x03
#define CUSTOM_REPORT_ID_4 0x04

void usb_hid_init() 
{
    stdio_init_all();

    gpio_set_function(0, GPIO_FUNC_USB);
    gpio_set_function(1, GPIO_FUNC_USB);

    if (usb_init()) 
	{
        printf("USB init failed\n");
        return;
    }

    if (usb_add_string_descriptor("RP2040 Volumer", 14, 1)) 
	{
        printf("Failed to add string descriptor\n");
        return;
    }

    usb_hid_set_report_descriptor(NULL, 0); // No custom descriptor for simplicity


	// Register the custom report IDs
    if (usb_start(VENDOR_ID, PRODUCT_ID, "The Purple Company", "volumer", "12345", "1.0", usb_default_handle_interrupt)) 
	{
        printf("Failed to start USB\n");
        return;
    }
}

void send_custom_message(uint8_t report_id, uint8_t* data, size_t length) 
{
    if (length > 64) 
	{
        printf("Data length exceeds report size\n");
        return;
    }

    hid_message_t message = {
        .report_id = report_id,
        .length = length,
    };

    memcpy(message.data, data, length);
    usb_hid_send_message(&message);
}

int main() 
{
    bi_decl(bi_program_name("Custom HID Program"));

    usb_hid_init();

    while (1) 
	{
        uint8_t msg1[] = "UP";
        uint8_t msg2[] = "DN";
        uint8_t msg3[] = "LF";
        uint8_t msg4[] = "RI";

        send_custom_message(CUSTOM_REPORT_ID_1, msg1, sizeof(msg1));
        //send_custom_message(CUSTOM_REPORT_ID_2, msg2, sizeof(msg2));
        //send_custom_message(CUSTOM_REPORT_ID_3, msg3, sizeof(msg3));
        //send_custom_message(CUSTOM_REPORT_ID_4, msg4, sizeof(msg4));

        sleep_ms(1000);
    }

    return 0;
}

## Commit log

2023-09-15 Added PCB and basic doc
    [bom.csv, bom.xls, designators.csv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]
2023-09-23 Working serial comm for +-1 Rotary encoder
    [rp2040.kicad_sch, volumer.kicad_sch]
2023-10-18 Finished PCB, not cheap enough, need to check components
    [bom.csv, designators.csv, positions.csv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]
2023-10-21 Added finished v0.2 PCB
    [bom.csv, bom.xls, designators.csv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]
2023-10-30 Working circuitpython code
    [volumer_v02.kicad_pcb]
2023-10-30 Added C program and instructions in readme
    [bom.csv, designators.csv, positions.csv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]
2023-11-13 Added PCB V1.0
    [bom.csv, designators.csv, positions.csv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]
2023-11-13 Removed schematics from docs
2024-03-26 Added pcb order instructions
    [bom.csv, case_v1.0.stl, designators.csv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]
2024-03-26 Added images
    [rp2040.kicad_sch, volumer_v1.0_bom.csv]
